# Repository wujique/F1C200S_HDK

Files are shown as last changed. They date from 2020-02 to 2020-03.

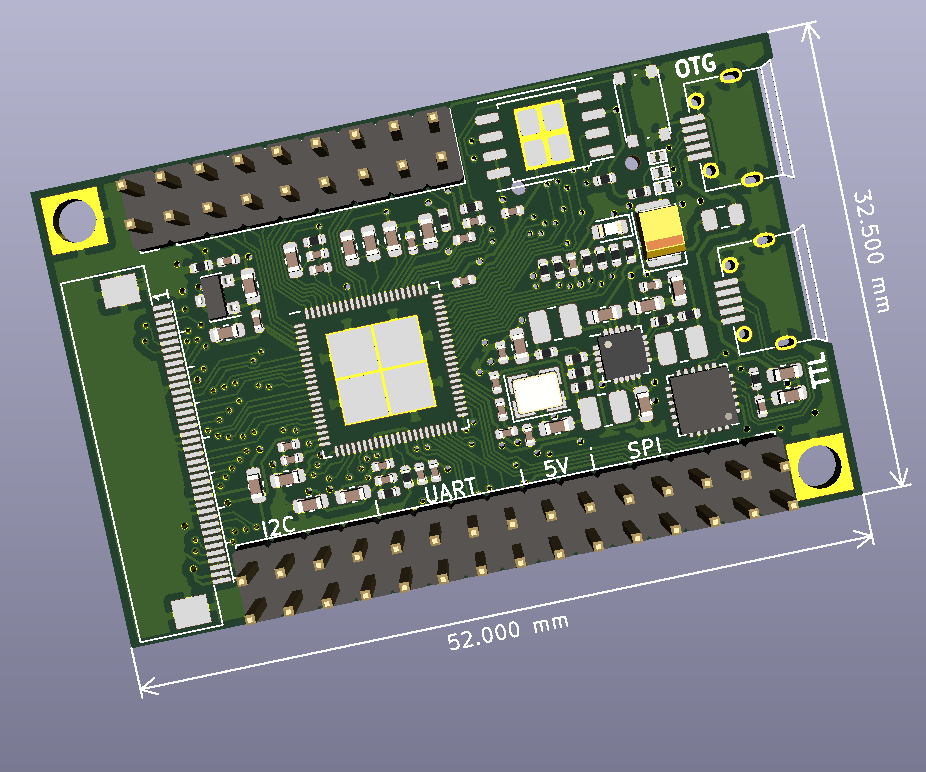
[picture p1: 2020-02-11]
doc/top.png

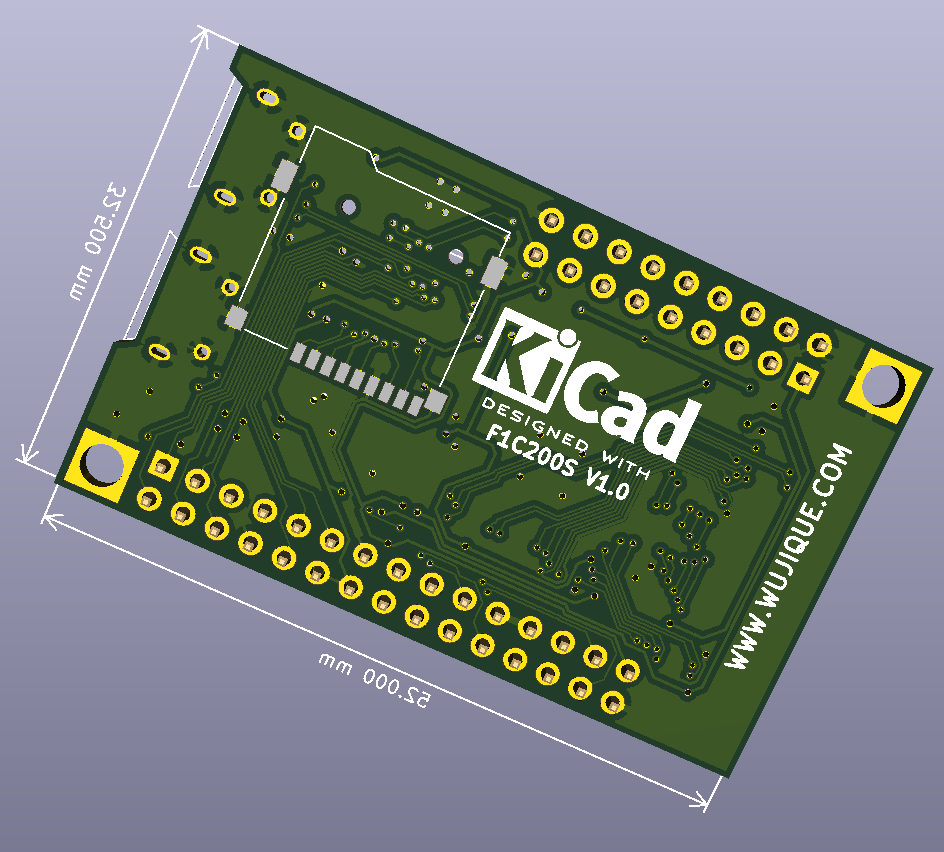
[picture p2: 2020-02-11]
doc/bottom.png

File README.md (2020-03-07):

## 说明

这是一个F1C200S小板的原理图和PCB。

挖坑网：https://whycan.cn/t_3688.html

用KiCAD 5.1.5绘制。

库基于WJQ，其他器件和封装是KiCAD自带库。

WJQ库：https://github.com/wujique/KiCAD_Lib

gerber目录是投板文件。

bom目录是器件丝印和资料，用InteractiveHtmlBom生成。

**2020-02-29**

已经验证：

USB下载固件到SPI FLASH能启动，TTL能进控制台，RGB LCD能显示、触摸屏。

可以从TF卡启动。

未验证：

TV和音频输出、外扩接口。

如有需要，请联系：www.wujique.com

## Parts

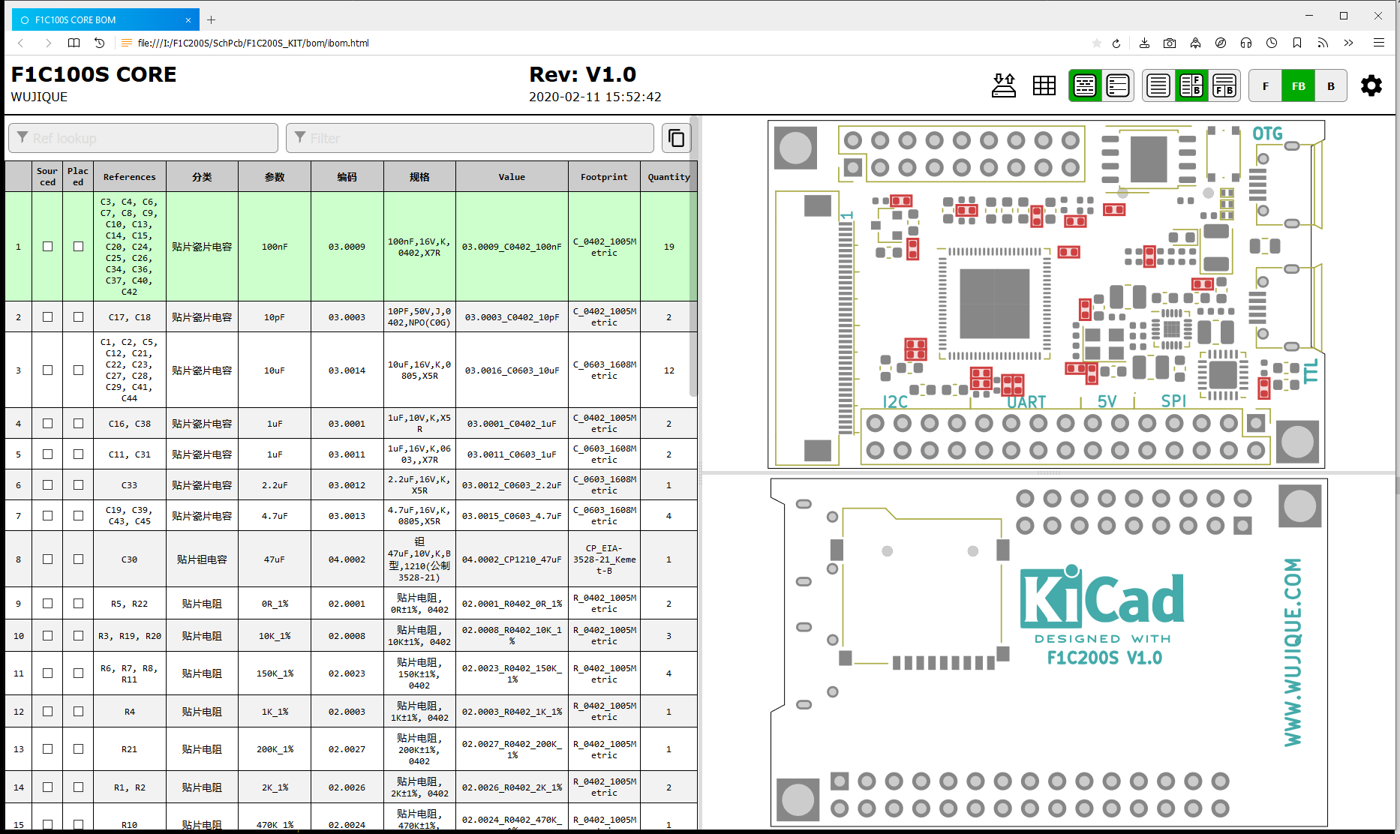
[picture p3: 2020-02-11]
doc/bom.png

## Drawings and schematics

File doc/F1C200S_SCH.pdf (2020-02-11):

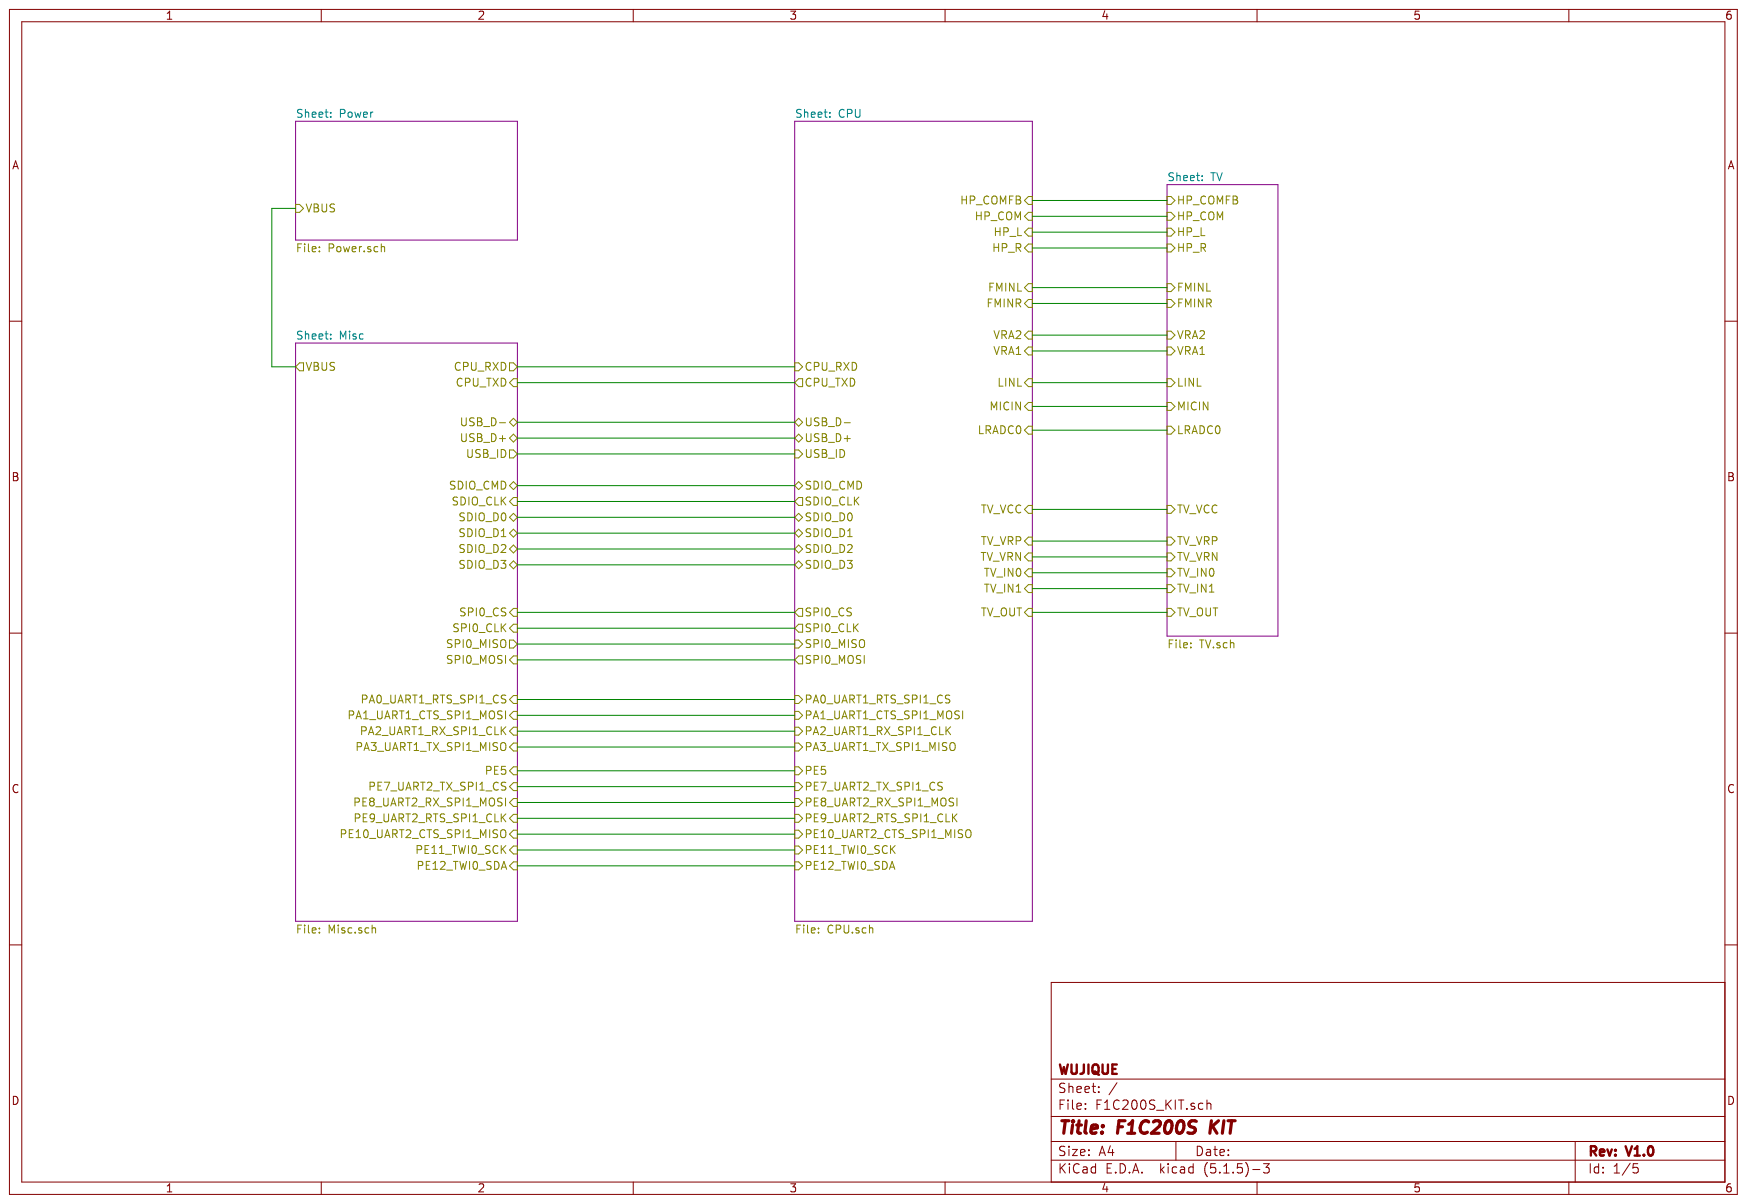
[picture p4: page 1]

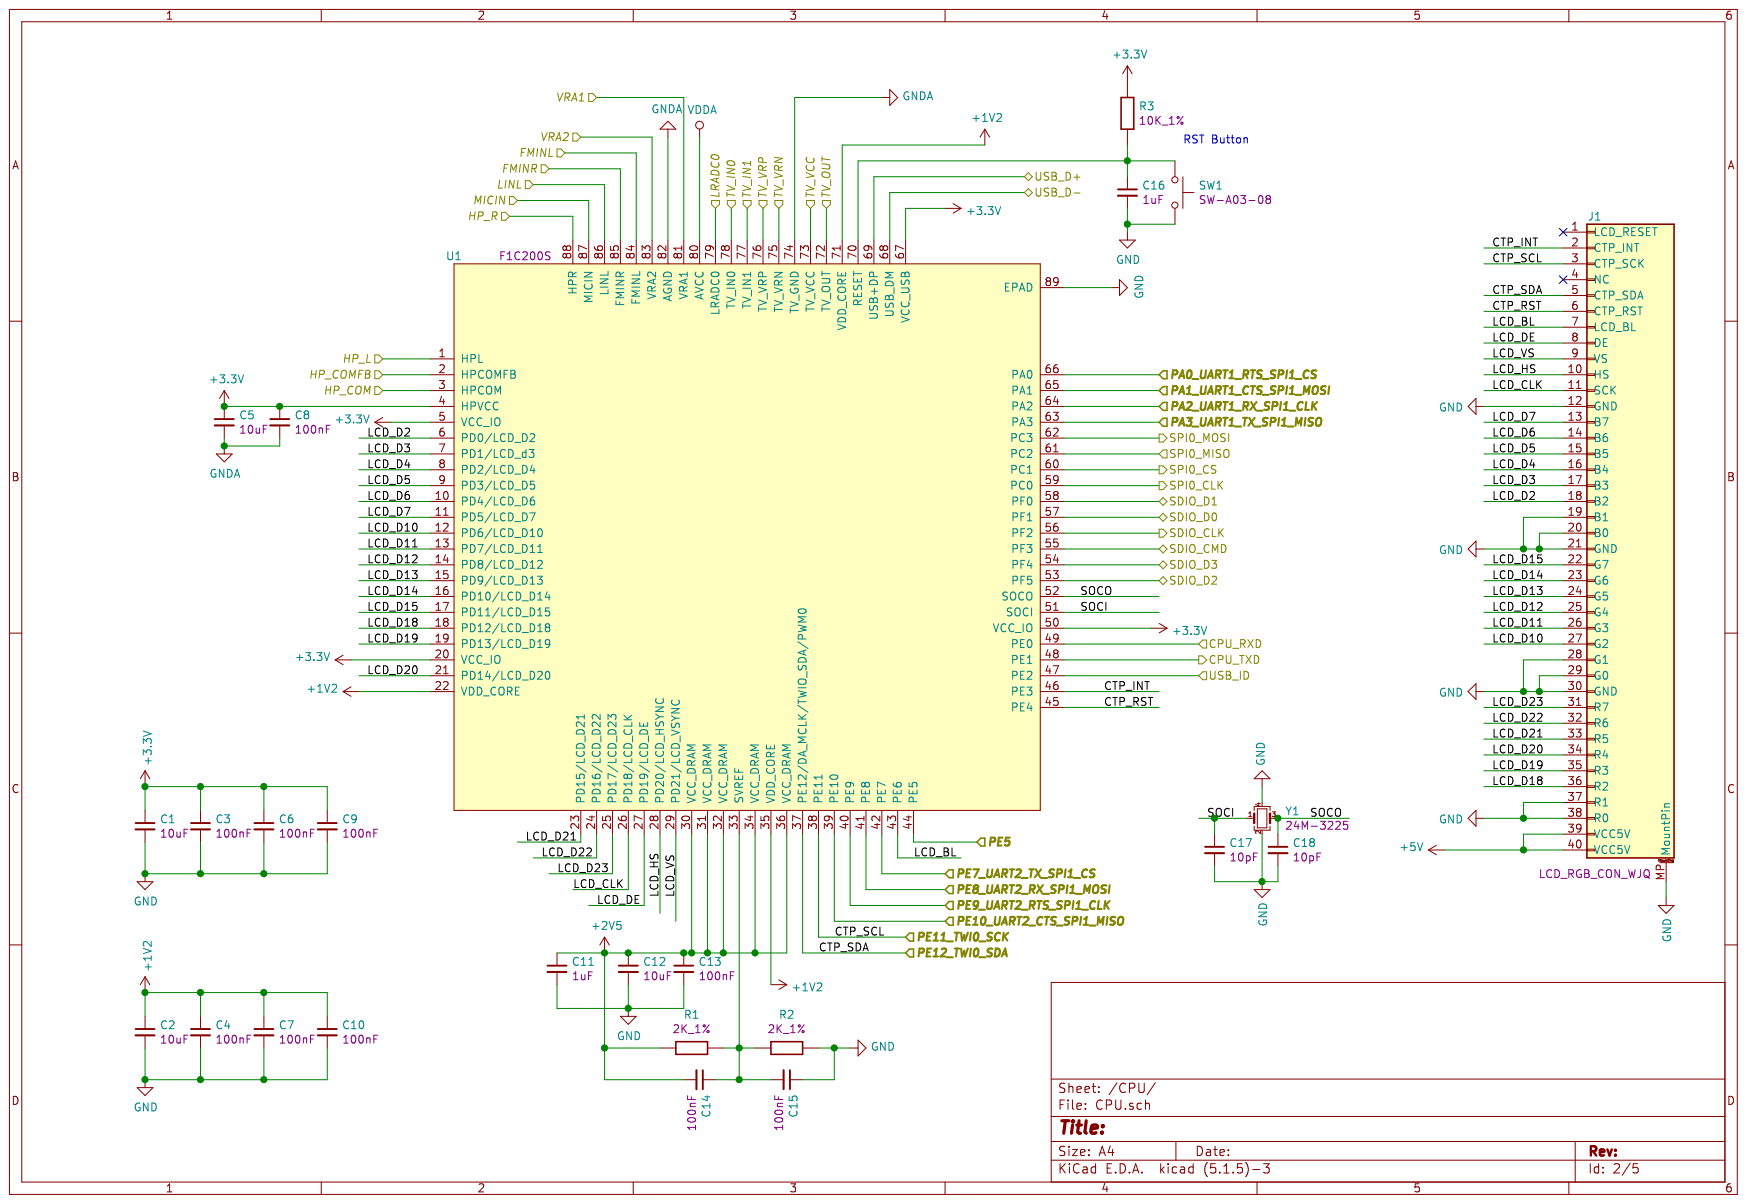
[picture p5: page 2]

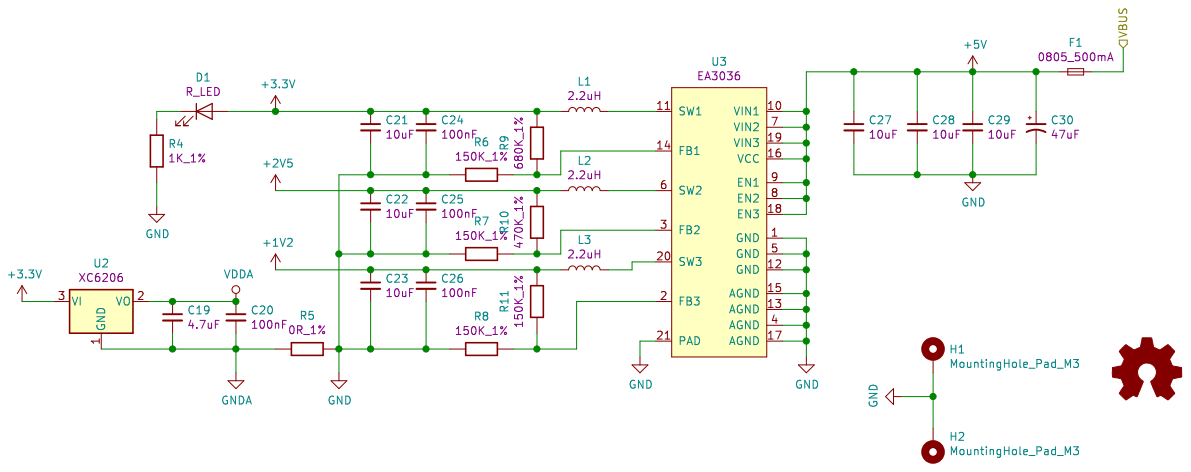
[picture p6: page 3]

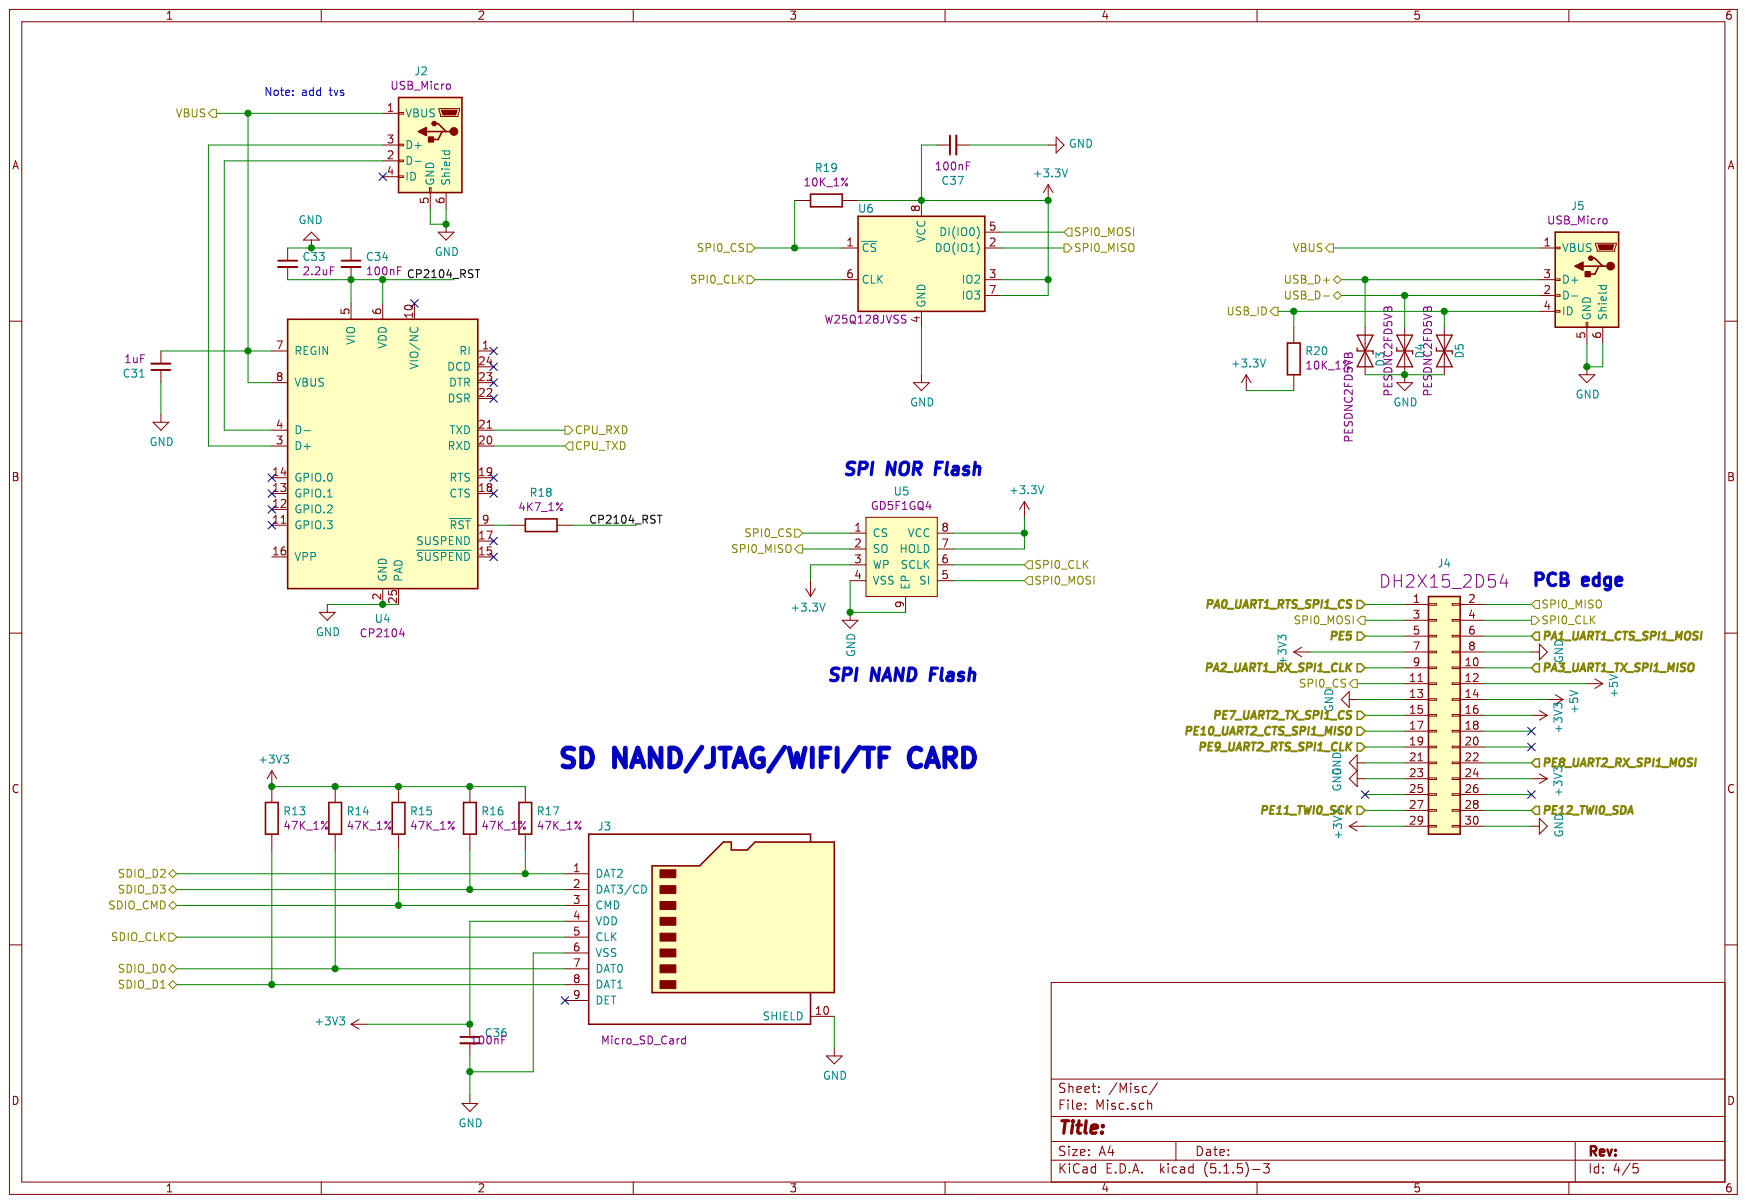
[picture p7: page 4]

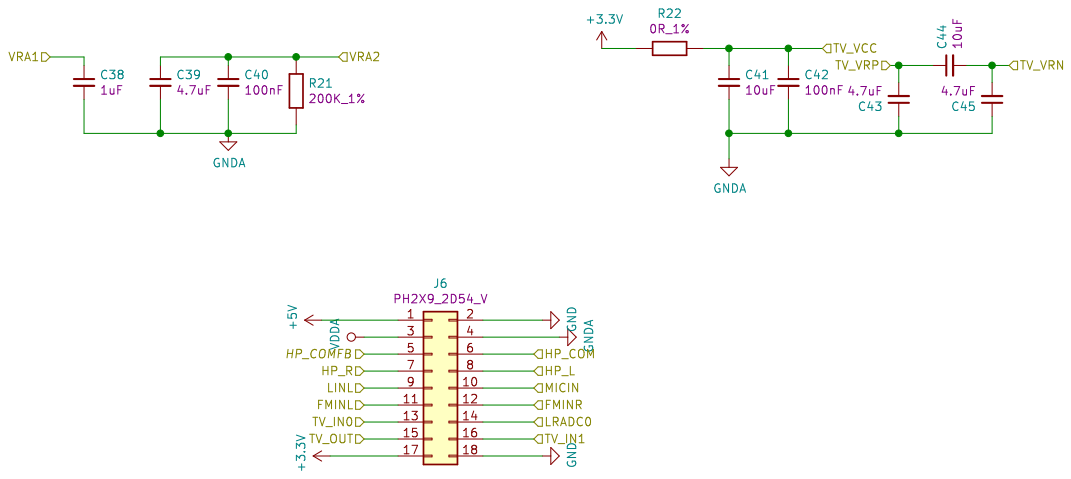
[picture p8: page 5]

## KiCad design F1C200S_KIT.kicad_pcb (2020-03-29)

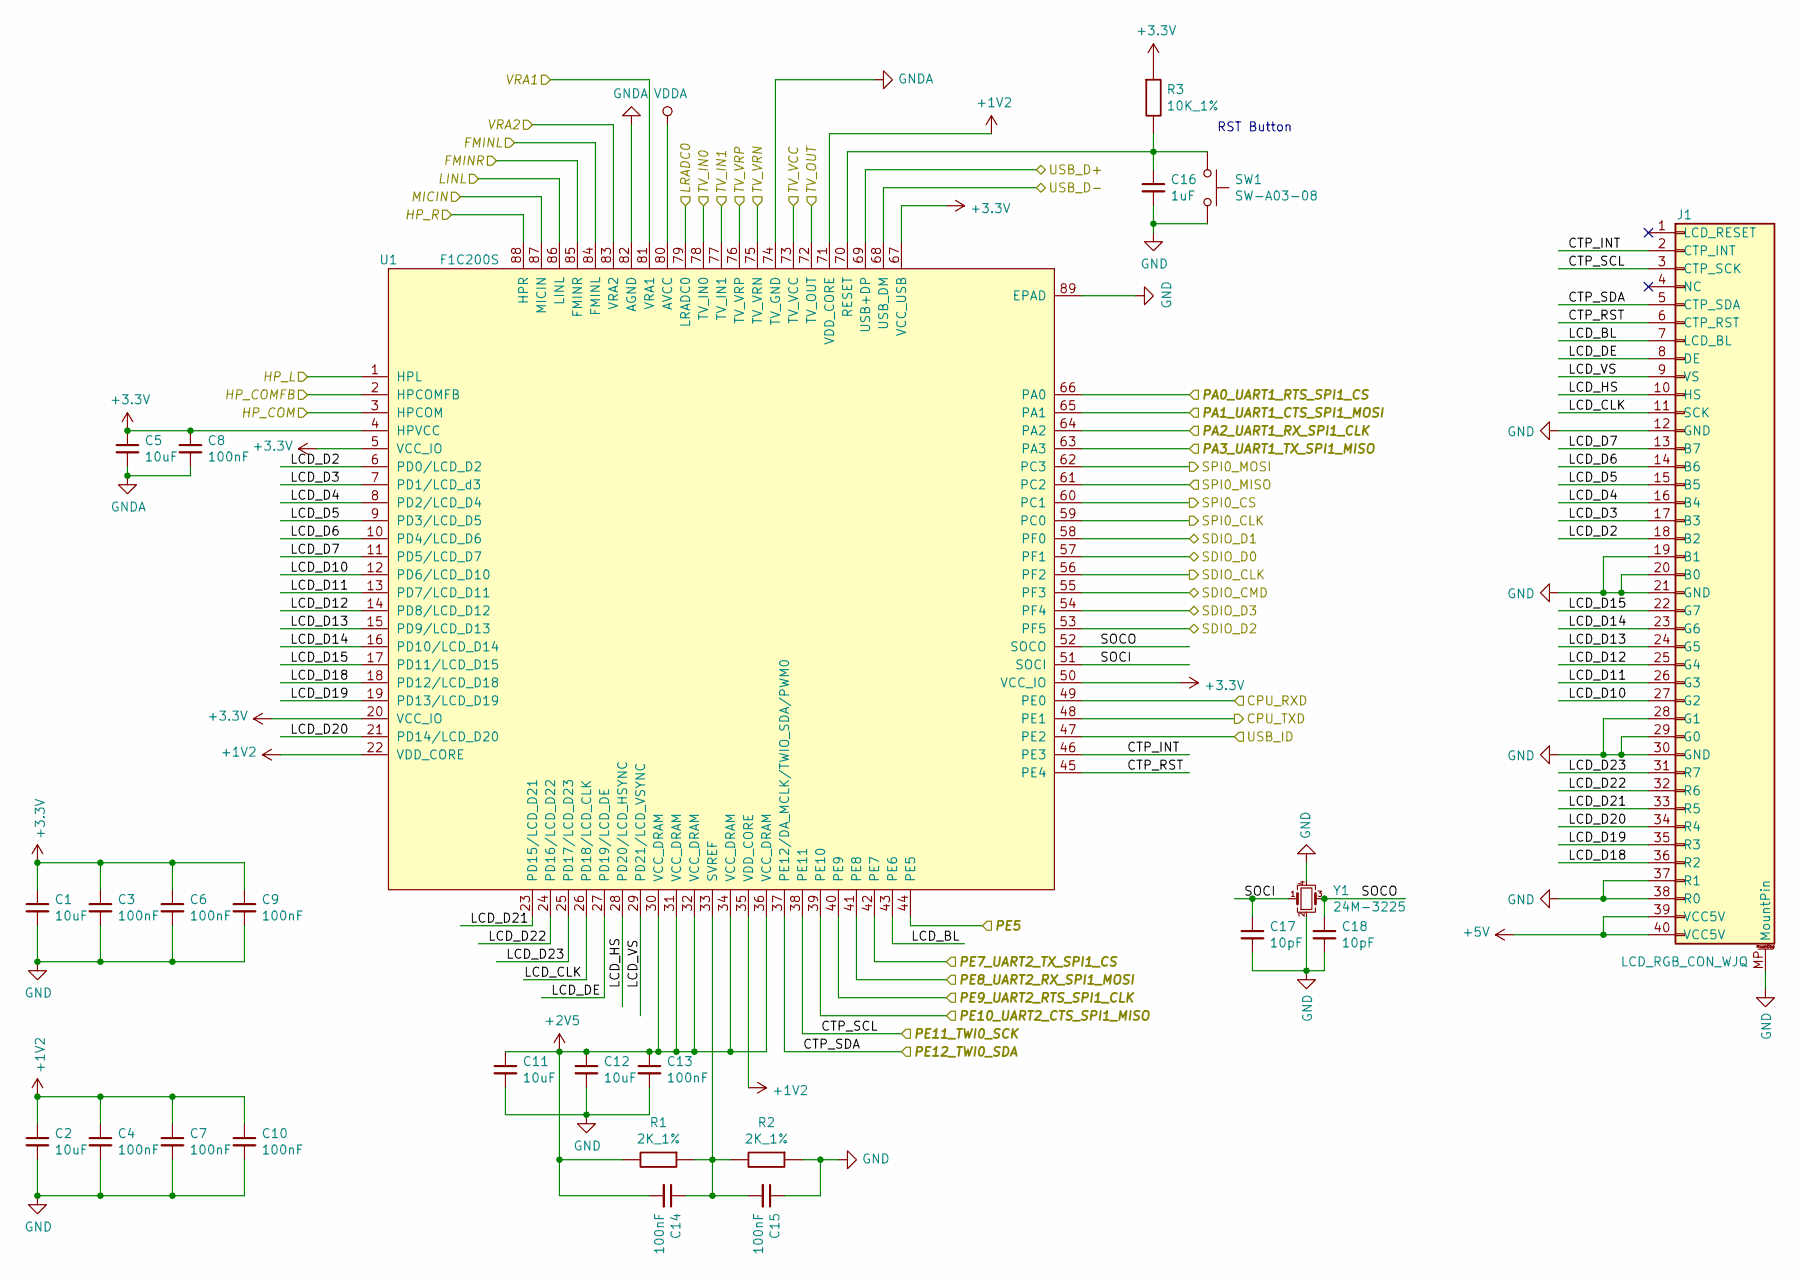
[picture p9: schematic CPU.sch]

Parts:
C1, C2, C5, C11, C12: 03.4004_C0603_10uF; C_0603_WJQ
C3, C4, C6, C7, C8, C9, C10, C13, C14, C15: 03.0009_C0402_100nF; C_0402_WJQ
C16: 03.0001_C0402_1uF; C_0402_WJQ
C17, C18: 03.0003_C0402_10pF; C_0402_WJQ
J1: 10.0402_LCD_RGB_CON_WJQ; FPC_40_0.5_BR
R1, R2: 02.0026_R0402_2K_1%; R_0402_WJQ
R3: 02.0008_R0402_10K_1%; R_0402_WJQ
SW1: 11.0101_SW-A03-08; SW_Push_Button__A03-08
U1: 08.0001_F1C200S; QFN-88_EP_10x10_Pitch0.4mm
Y1: 07.0403_Crystal_24M_3225; Crystal_SMD_3225-4Pin_3.2x2.5mm

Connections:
+1V2: C2.1, C4.1, C7.1, C10.1, U1.22 (VDD_CORE), U1.35 (VDD_CORE), U1.71 (VDD_CORE); also elsewhere on the board
+2V5: C11.1, C12.1, C13.1, C14.2, R1.2, U1.30 (VCC_DRAM), U1.31 (VCC_DRAM), U1.32 (VCC_DRAM), U1.34 (VCC_DRAM), U1.36 (VCC_DRAM); also elsewhere on the board
+5V: J1.39 (VCC5V), J1.40 (VCC5V); also elsewhere on the board
/CPU/CPU_RXD: U1.49 (PE0); also elsewhere on the board
/CPU/CPU_TXD: U1.48 (PE1); also elsewhere on the board
/CPU/CTP_INT: J1.2 (CTP_INT), U1.46 (PE3)
/CPU/CTP_RST: J1.6 (CTP_RST), U1.45 (PE4)
/CPU/FMINL: U1.84 (FMINL); also elsewhere on the board
/CPU/FMINR: U1.85 (FMINR); also elsewhere on the board
/CPU/HP_COM: U1.3 (HPCOM); also elsewhere on the board
/CPU/HP_COMFB: U1.2 (HPCOMFB); also elsewhere on the board
/CPU/HP_L: U1.1 (HPL); also elsewhere on the board
/CPU/HP_R: U1.88 (HPR); also elsewhere on the board
/CPU/LCD_BL: J1.7 (LCD_BL), U1.43 (PE6)
/CPU/LCD_CLK: J1.11 (SCK), U1.26 (PD18/LCD_CLK)
/CPU/LCD_D2: J1.18 (B2), U1.6 (PD0/LCD_D2)
/CPU/LCD_D3: J1.17 (B3), U1.7 (PD1/LCD_d3)
/CPU/LCD_D4: J1.16 (B4), U1.8 (PD2/LCD_D4)
/CPU/LCD_D5: J1.15 (B5), U1.9 (PD3/LCD_D5)
/CPU/LCD_D6: J1.14 (B6), U1.10 (PD4/LCD_D6)
/CPU/LCD_D7: J1.13 (B7), U1.11 (PD5/LCD_D7)
/CPU/LCD_D10: J1.27 (G2), U1.12 (PD6/LCD_D10)
/CPU/LCD_D11: J1.26 (G3), U1.13 (PD7/LCD_D11)
/CPU/LCD_D12: J1.25 (G4), U1.14 (PD8/LCD_D12)
/CPU/LCD_D13: J1.24 (G5), U1.15 (PD9/LCD_D13)
/CPU/LCD_D14: J1.23 (G6), U1.16 (PD10/LCD_D14)
/CPU/LCD_D15: J1.22 (G7), U1.17 (PD11/LCD_D15)
/CPU/LCD_D18: J1.36 (R2), U1.18 (PD12/LCD_D18)
/CPU/LCD_D19: J1.35 (R3), U1.19 (PD13/LCD_D19)
/CPU/LCD_D20: J1.34 (R4), U1.21 (PD14/LCD_D20)
/CPU/LCD_D21: J1.33 (R5), U1.23 (PD15/LCD_D21)
/CPU/LCD_D22: J1.32 (R6), U1.24 (PD16/LCD_D22)
/CPU/LCD_D23: J1.31 (R7), U1.25 (PD17/LCD_D23)
/CPU/LCD_DE: J1.8 (DE), U1.27 (PD19/LCD_DE)
/CPU/LCD_HS: J1.10 (HS), U1.28 (PD20/LCD_HSYNC)
/CPU/LCD_VS: J1.9 (VS), U1.29 (PD21/LCD_VSYNC)
/CPU/LINL: U1.86 (LINL); also elsewhere on the board
/CPU/LRADC0: U1.79 (LRADC0); also elsewhere on the board
/CPU/MICIN: U1.87 (MICIN); also elsewhere on the board
/CPU/PA0_UART1_RTS_SPI1_CS: U1.66 (PA0); also elsewhere on the board
/CPU/PA1_UART1_CTS_SPI1_MOSI: U1.65 (PA1); also elsewhere on the board
/CPU/PA2_UART1_RX_SPI1_CLK: U1.64 (PA2); also elsewhere on the board
/CPU/PA3_UART1_TX_SPI1_MISO: U1.63 (PA3); also elsewhere on the board
/CPU/PE5: U1.44 (PE5); also elsewhere on the board
/CPU/PE7_UART2_TX_SPI1_CS: U1.42 (PE7); also elsewhere on the board
/CPU/PE8_UART2_RX_SPI1_MOSI: U1.41 (PE8); also elsewhere on the board
/CPU/PE9_UART2_RTS_SPI1_CLK: U1.40 (PE9); also elsewhere on the board
/CPU/PE10_UART2_CTS_SPI1_MISO: U1.39 (PE10); also elsewhere on the board
/CPU/PE11_TWI0_SCK: J1.3 (CTP_SCK), U1.38 (PE11); also elsewhere on the board
/CPU/PE12_TWI0_SDA: J1.5 (CTP_SDA), U1.37 (PE12/DA_MCLK/TWIO_SDA/PWM0); also elsewhere on the board
/CPU/SDIO_CLK: U1.56 (PF2); also elsewhere on the board
/CPU/SDIO_CMD: U1.55 (PF3); also elsewhere on the board
/CPU/SDIO_D0: U1.57 (PF1); also elsewhere on the board
/CPU/SDIO_D1: U1.58 (PF0); also elsewhere on the board
/CPU/SDIO_D2: U1.53 (PF5); also elsewhere on the board
/CPU/SDIO_D3: U1.54 (PF4); also elsewhere on the board
/CPU/SOCI: C17.1, U1.51 (SOCI), Y1.1
/CPU/SOCO: C18.1, U1.52 (SOCO), Y1.3
/CPU/SPI0_CLK: U1.59 (PC0); also elsewhere on the board
/CPU/SPI0_CS: U1.60 (PC1); also elsewhere on the board
/CPU/SPI0_MISO: U1.61 (PC2); also elsewhere on the board
/CPU/SPI0_MOSI: U1.62 (PC3); also elsewhere on the board
/CPU/TV_IN0: U1.78 (TV_IN0); also elsewhere on the board
/CPU/TV_IN1: U1.77 (TV_IN1); also elsewhere on the board
/CPU/TV_OUT: U1.72 (TV_OUT); also elsewhere on the board
/CPU/TV_VCC: U1.73 (TV_VCC); also elsewhere on the board
/CPU/TV_VRN: U1.75 (TV_VRN); also elsewhere on the board
/CPU/TV_VRP: U1.76 (TV_VRP); also elsewhere on the board
/CPU/USB_D+: U1.69 (USB+DP); also elsewhere on the board
/CPU/USB_D-: U1.68 (USB_DM); also elsewhere on the board
/CPU/USB_ID: U1.47 (PE2); also elsewhere on the board
/CPU/VRA1: U1.81 (VRA1); also elsewhere on the board
/CPU/VRA2: U1.83 (VRA2); also elsewhere on the board
GND: C1.2, C2.2, C3.2, C4.2, C6.2, C7.2, C9.2, C10.2, C11.2, C12.2, C13.2, C15.1, C16.2, C17.2, C18.2, J1.12 (GND), J1.19 (B1), J1.20 (B0), J1.21 (GND), J1.28 (G1), J1.29 (G0), J1.30 (GND), J1.37 (R1), J1.38 (R0), J1.MP (MountPin), R2.1, SW1.2, U1.89 (EPAD), Y1.2, Y1.4; also elsewhere on the board
GNDA: C5.2, C8.2, U1.74 (TV_GND), U1.82 (AGND); also elsewhere on the board
unnamed: C14.1, C15.2, R1.1, R2.2, U1.33 (SVREF)
unnamed: C16.1, R3.2, SW1.1, U1.70 (RESET)
VDDA: U1.80 (AVCC); also elsewhere on the board

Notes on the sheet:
RST Button

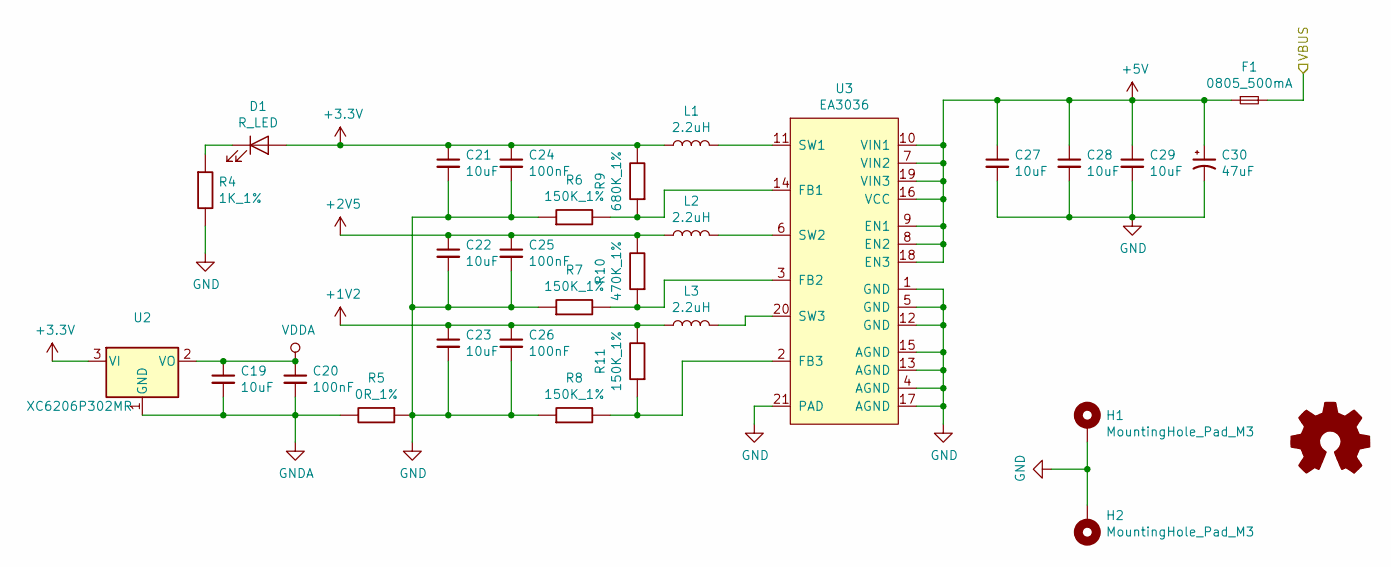
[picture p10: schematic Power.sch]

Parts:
C19, C21, C22, C23, C27, C28, C29: 03.4004_C0603_10uF; C_0603_WJQ
C20, C24, C25, C26: 03.0009_C0402_100nF; C_0402_WJQ
C30: 04.0002_CP1210_47uF; CP_EIA-3528-21_Kemet-B
D1: 07.0201_LED_Red_0603; LED_0603_1608Metric
F1: 07.0004_Fuse_0805_500mA; Fuse_0805_2012Metric
H1, H2: MountingHole_Pad_M3; MP_HOLE_L4_M3
L1, L2, L3: 06.0102_L2520_2.2uH; L_1008_2520_WJQ
LOGO1: Logo_Open_Hardware_Small; KiCad-Logo2_6mm_SilkScreen
R4: 02.0003_R0402_1K_1%; R_0402_WJQ
R5: 02.0001_R0402_0R_1%; R_0402_WJQ
R6, R7, R8, R11: 02.0023_R0402_150K_1%; R_0402_WJQ
R9: 02.0025_R0402_680K_1%; R_0402_WJQ
R10: 02.0024_R0402_470K_1%; R_0402_WJQ
U2: 09.0103_XC6206; SOT-23
U3: 09.0102_EA3036; QFN-20_EP_3x3_Pitch0.4mm

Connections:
+1V2: C23.1, C26.1, L3.1, R11.2; also elsewhere on the board
+2V5: C22.1, C25.1, L2.1, R10.2; also elsewhere on the board
+5V: C27.1, C28.1, C29.1, C30.1, F1.1, U3.7 (VIN2), U3.8 (EN2), U3.9 (EN1), U3.10 (VIN1), U3.16 (VCC), U3.18 (EN3), U3.19 (VIN3); also elsewhere on the board
/Misc/VBUS: F1.2; also elsewhere on the board
GND: C21.2, C22.2, C23.2, C24.2, C25.2, C26.2, C27.2, C28.2, C29.2, C30.2, H1.1, H2.1, R4.2, R5.1, R6.1, R7.1, R8.1, U3.1 (GND), U3.4 (AGND), U3.5 (GND), U3.12 (GND), U3.13 (AGND), U3.15 (AGND), U3.17 (AGND), U3.21 (PAD); also elsewhere on the board
GNDA: C19.2, C20.2, R5.2, U2.1 (GND); also elsewhere on the board
unnamed: D1.1 (K), R4.1
unnamed: L1.2, U3.11 (SW1)
unnamed: L2.2, U3.6 (SW2)
unnamed: L3.2, U3.20 (SW3)
unnamed: R6.2, R9.1, U3.14 (FB1)
unnamed: R7.2, R10.1, U3.3 (FB2)
unnamed: R8.2, R11.1, U3.2 (FB3)
VDDA: C19.1, C20.1, U2.2 (VO); also elsewhere on the board

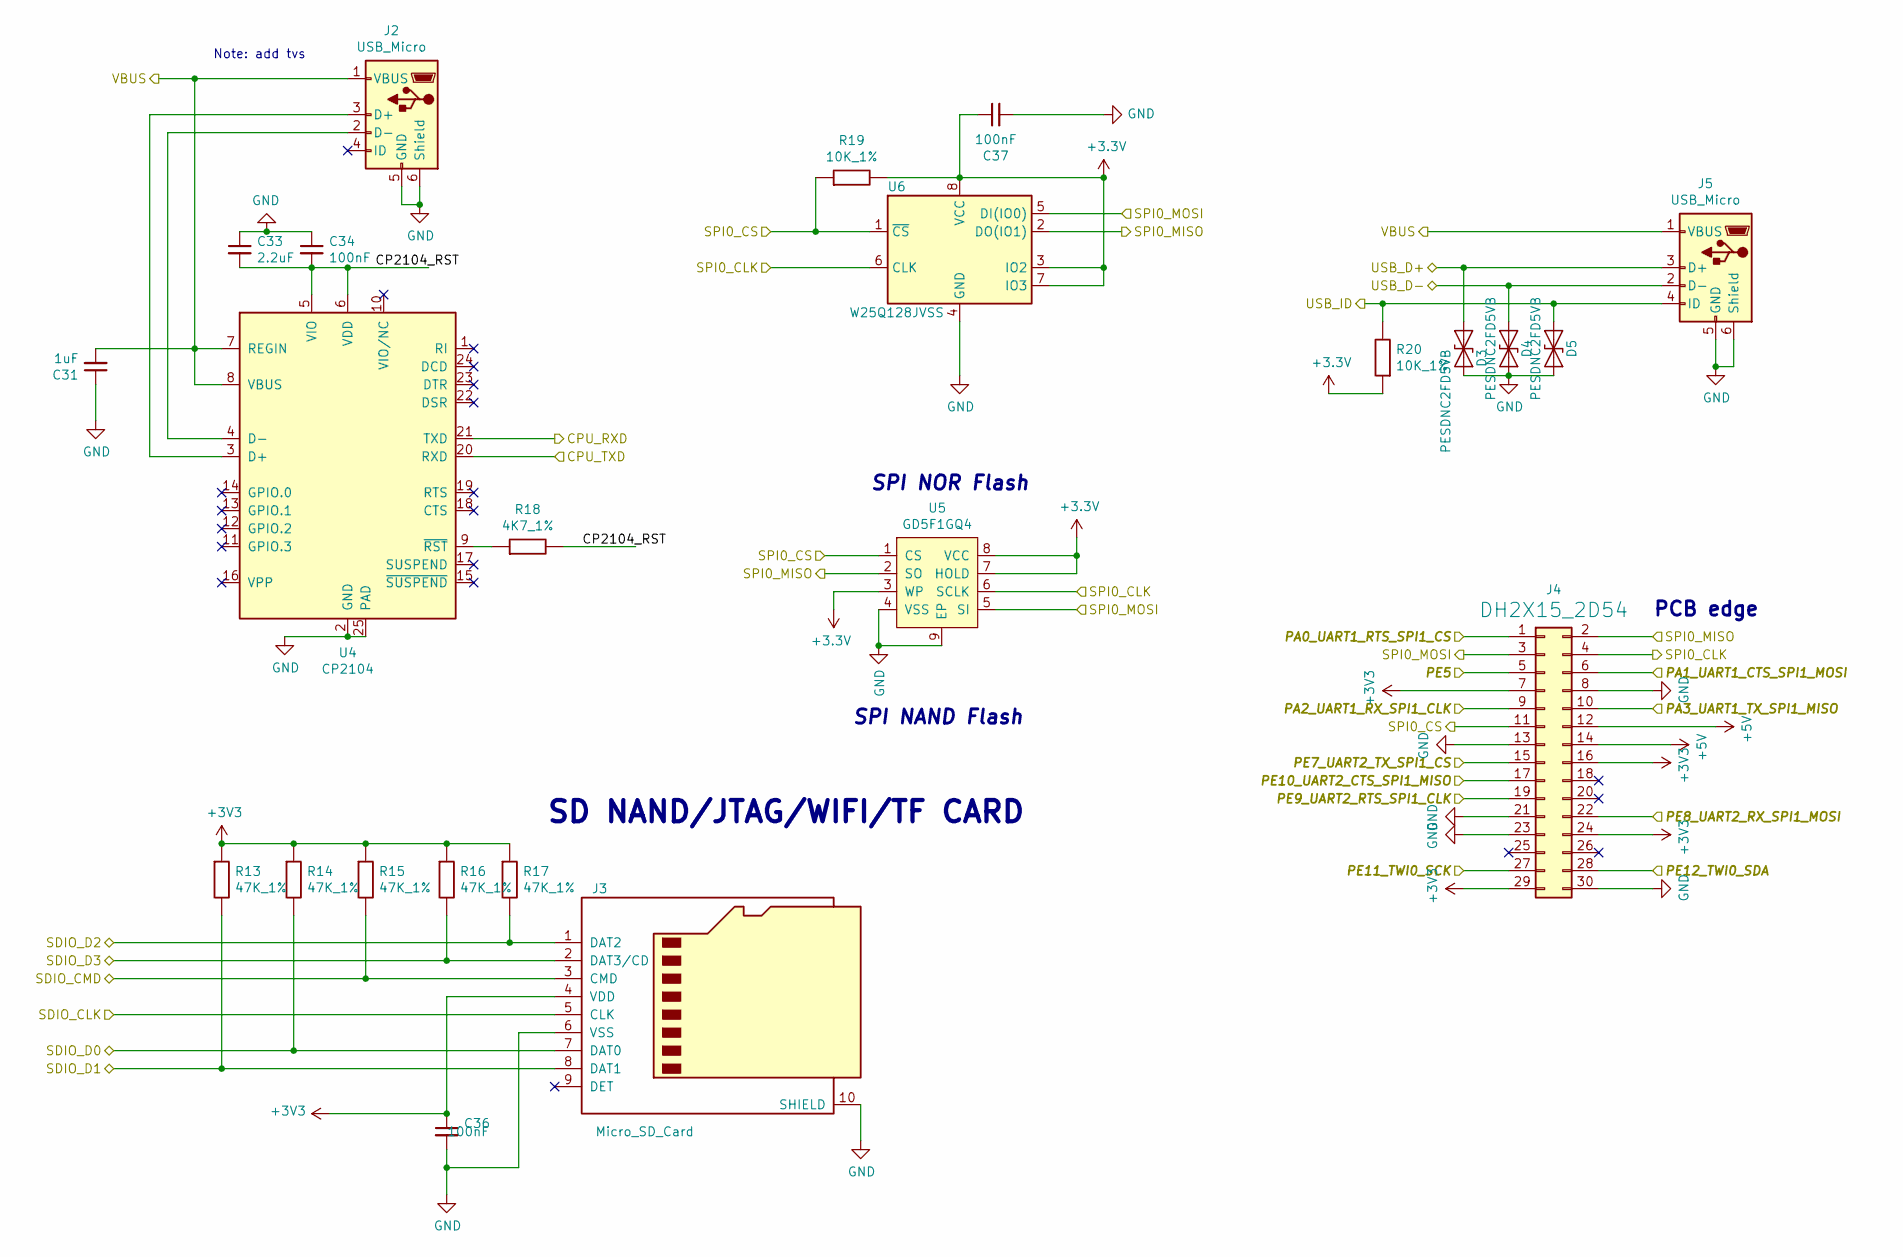
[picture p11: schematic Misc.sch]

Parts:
C31: 03.4001_C0603_1uF; C_0603_WJQ
C33: 03.4002_C0603_2.2uF; C_0603_WJQ
C34, C36, C37: 03.0009_C0402_100nF; C_0402_WJQ
D3, D4, D5: 07.0002_D_TVS_PESDNC2FD5VB; DFN1006-2L
J2, J5: 10.0002_USB_Micro; MicroUSB_5S_B_A01SB141B1-067
J3: 10.0001_Micro_SD_Card; microSD_HRO_TF_01A
J4: 10.0201_PH2X15_2D54_V; PinHeader_2x15_P2.54mm_Vertical
R13, R14, R15, R16, R17: 02.0014_R0402_47K_1%; R_0402_WJQ
R18: 02.0005_R0402_4K7_1%; R_0402_WJQ
R19, R20: 02.0008_R0402_10K_1%; R_0402_WJQ
U4: 09.0001_CP2104; QFN-24-1EP_4x4mm_P0.5mm_EP2.6x2.6mm
U5: 09.0303_GD5F1GQ4; WSON-8-1EP_8x6mm_P1.27mm_EP3.4x4.3mm
U6: 09.0302_W25Q128JVS; SOIC-8_5.23x5.23mm_P1.27mm

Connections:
+5V: J4.12, J4.14; also elsewhere on the board
/CPU/CPU_RXD: U4.21 (TXD); also elsewhere on the board
/CPU/CPU_TXD: U4.20 (RXD); also elsewhere on the board
/CPU/PA0_UART1_RTS_SPI1_CS: J4.1; also elsewhere on the board
/CPU/PA1_UART1_CTS_SPI1_MOSI: J4.6; also elsewhere on the board
/CPU/PA2_UART1_RX_SPI1_CLK: J4.9; also elsewhere on the board
/CPU/PA3_UART1_TX_SPI1_MISO: J4.10; also elsewhere on the board
/CPU/PE5: J4.5; also elsewhere on the board
/CPU/PE7_UART2_TX_SPI1_CS: J4.15; also elsewhere on the board
/CPU/PE8_UART2_RX_SPI1_MOSI: J4.22; also elsewhere on the board
/CPU/PE9_UART2_RTS_SPI1_CLK: J4.19; also elsewhere on the board
/CPU/PE10_UART2_CTS_SPI1_MISO: J4.17; also elsewhere on the board
/CPU/PE11_TWI0_SCK: J4.27; also elsewhere on the board
/CPU/PE12_TWI0_SDA: J4.28; also elsewhere on the board
/CPU/SDIO_CLK: J3.5 (CLK); also elsewhere on the board
/CPU/SDIO_CMD: J3.3 (CMD), R15.2; also elsewhere on the board
/CPU/SDIO_D0: J3.7 (DAT0), R14.2; also elsewhere on the board
/CPU/SDIO_D1: J3.8 (DAT1), R13.2; also elsewhere on the board
/CPU/SDIO_D2: J3.1 (DAT2), R17.2; also elsewhere on the board
/CPU/SDIO_D3: J3.2 (DAT3/CD), R16.2; also elsewhere on the board
/CPU/SPI0_CLK: J4.4, U5.6 (SCLK), U6.6 (CLK); also elsewhere on the board
/CPU/SPI0_CS: J4.11, R19.1, U5.1 (CS), U6.1 (~CS); also elsewhere on the board
/CPU/SPI0_MISO: J4.2, U5.2 (SO), U6.2 (DO(IO1)); also elsewhere on the board
/CPU/SPI0_MOSI: J4.3, U5.5 (SI), U6.5 (DI(IO0)); also elsewhere on the board
/CPU/USB_D+: D3.1 (A1), J5.3 (D+); also elsewhere on the board
/CPU/USB_D-: D4.1 (A1), J5.2 (D-); also elsewhere on the board
/CPU/USB_ID: D5.1 (A1), J5.4 (ID), R20.2; also elsewhere on the board
/Misc/CP2104_RST: C33.2, C34.2, R18.2, U4.5 (VIO), U4.6 (VDD)
/Misc/VBUS: C31.2, J2.1 (VBUS), J5.1 (VBUS), U4.7 (REGIN), U4.8 (VBUS); also elsewhere on the board
GND: C31.1, C33.1, C34.1, C36.2, C37.2, D3.2 (A2), D4.2 (A2), D5.2 (A2), J2.5 (GND), J2.6 (Shield), J3.6 (VSS), J3.10 (SHIELD), J4.8, J4.13, J4.21, J4.23, J4.30, J5.5 (GND), J5.6 (Shield), U4.2 (GND), U4.25 (PAD), U5.4 (VSS), U5.9 (EP), U6.4 (GND); also elsewhere on the board
unnamed: J2.2 (D-), U4.4 (D-)
unnamed: J2.3 (D+), U4.3 (D+)
unnamed: R18.1, U4.9 (~RST)

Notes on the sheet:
Note: add tvs
SPI NOR Flash
SD NAND/JTAG/WIFI/TF CARD
PCB edge
SPI NAND Flash

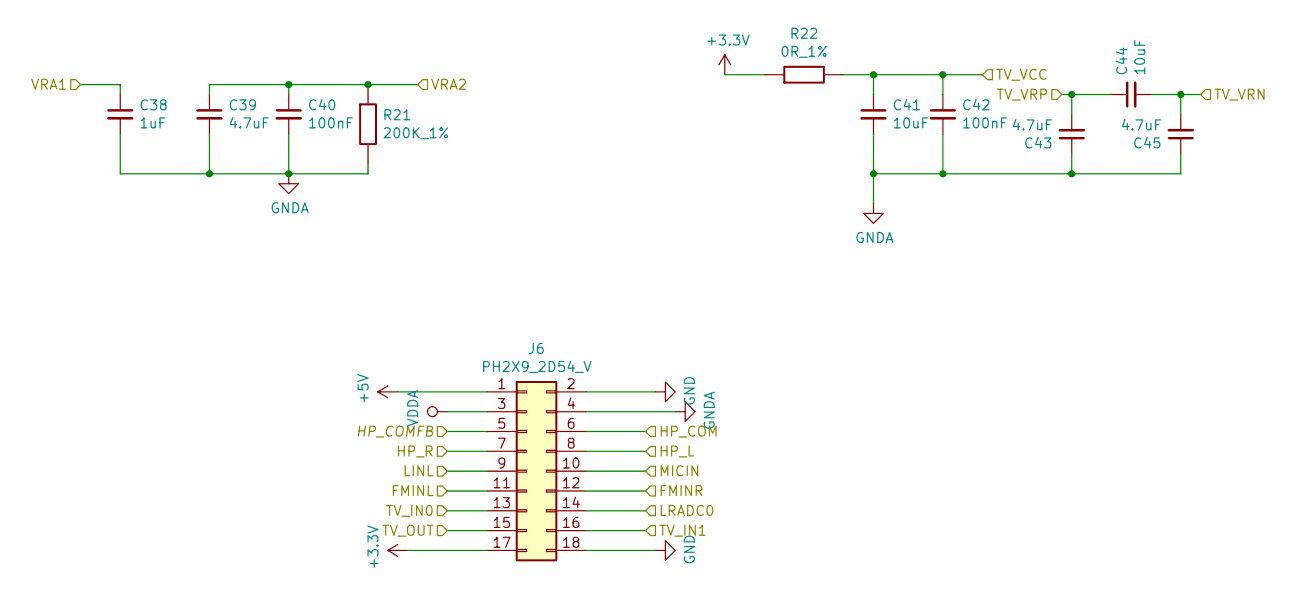
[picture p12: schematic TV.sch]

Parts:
C38: 03.0001_C0402_1uF; C_0402_WJQ
C39, C43, C45: 03.4003_C0603_4.7uF; C_0603_WJQ
C40, C42: 03.0009_C0402_100nF; C_0402_WJQ
C41: 03.4004_C0603_10uF; C_0603_WJQ
C44: 03.0016_C0603_10uF; C_0603_1608Metric
J6: 10.0202_PH2X9_2D54_V; PinHeader_2x09_P2.54mm_Vertical
R21: 02.0027_R0402_200K_1%; R_0402_WJQ
R22: 02.0001_R0402_0R_1%; R_0402_WJQ

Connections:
+5V: J6.1; also elsewhere on the board
/CPU/FMINL: J6.11; also elsewhere on the board
/CPU/FMINR: J6.12; also elsewhere on the board
/CPU/HP_COM: J6.6; also elsewhere on the board
/CPU/HP_COMFB: J6.5; also elsewhere on the board
/CPU/HP_L: J6.8; also elsewhere on the board
/CPU/HP_R: J6.7; also elsewhere on the board
/CPU/LINL: J6.9; also elsewhere on the board
/CPU/LRADC0: J6.14; also elsewhere on the board
/CPU/MICIN: J6.10; also elsewhere on the board
/CPU/TV_IN0: J6.13; also elsewhere on the board
/CPU/TV_IN1: J6.16; also elsewhere on the board
/CPU/TV_OUT: J6.15; also elsewhere on the board
/CPU/TV_VCC: C41.1, C42.1, R22.2; also elsewhere on the board
/CPU/TV_VRN: C44.2, C45.2; also elsewhere on the board
/CPU/TV_VRP: C43.2, C44.1; also elsewhere on the board
/CPU/VRA1: C38.1; also elsewhere on the board
/CPU/VRA2: C39.1, C40.1, R21.1; also elsewhere on the board
GND: J6.2, J6.18; also elsewhere on the board
GNDA: C38.2, C39.2, C40.2, C41.2, C42.2, C43.1, C45.1, J6.4, R21.2; also elsewhere on the board
VDDA: J6.3; also elsewhere on the board

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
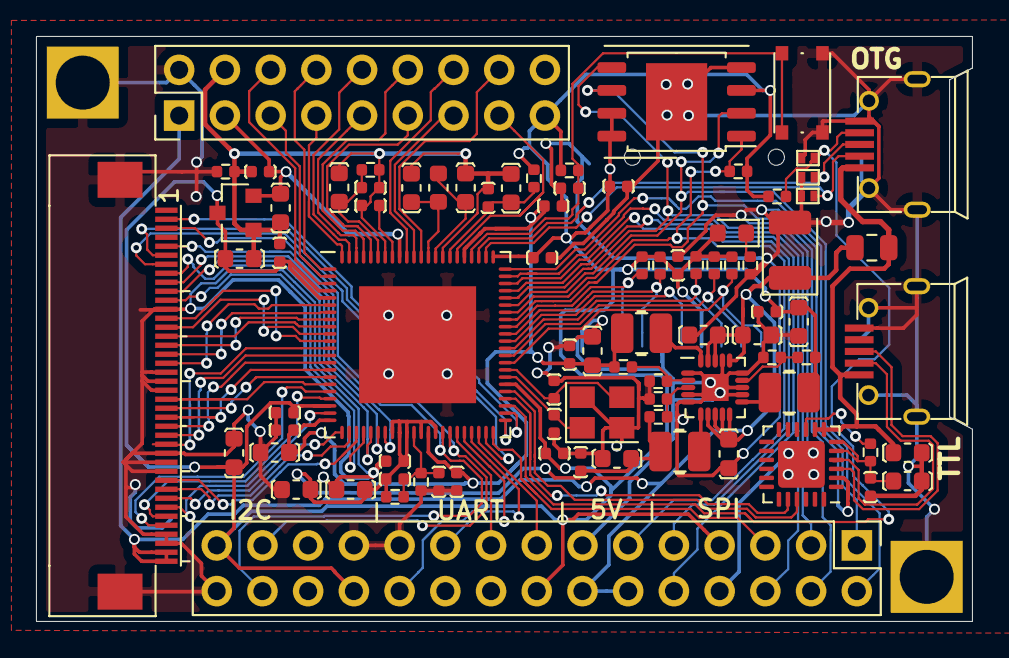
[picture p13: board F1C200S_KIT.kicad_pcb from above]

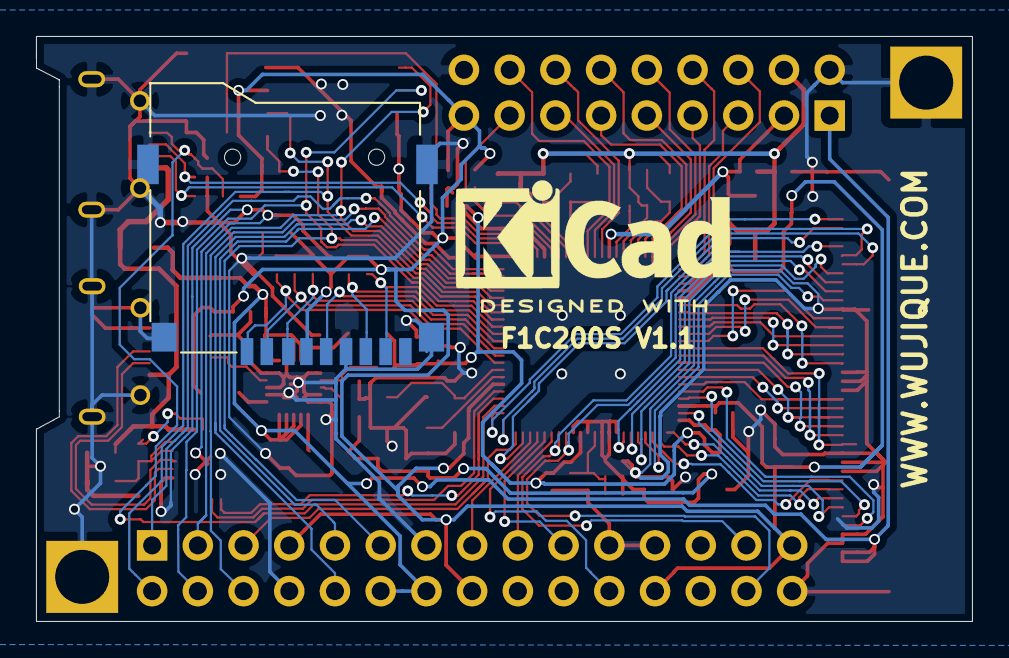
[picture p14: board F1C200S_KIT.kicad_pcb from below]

Board: 2 copper layers, 52.0 x 32.5 mm, 89 parts (2 on the bottom side), 91 nets.

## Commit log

2020-02-11 绘制完成，未投板验证
    [CPU.sch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]
2020-02-11 修改边框，出gerber，添加pdf格式原理图
    [F1C200S_KIT-B_Cu.gbr, F1C200S_KIT-B_Mask.gbr, F1C200S_KIT-B_Paste.gbr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]
2020-02-12 修改BOM，添加TF卡和USB、按键的购买链接
2020-02-12 增加器件库链接
2020-02-16 修改XC6206信息，明确型号为3.0V输出
    [F1C200S_KIT.kicad_pcb, Power.sch]
2020-02-25 修改README, 板子大部分功能已经验证
2020-02-29 触摸屏已经验证，修改readme
2020-03-07 增加挖坑网连接
2020-03-29 优化封装外形丝印，PCB进行拼板处理
    [CPU.sch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]
2020-03-29 修改靠近板边的地线，解决锣板掏线问题
    [F1C200S_KIT.kicad_pcb]
